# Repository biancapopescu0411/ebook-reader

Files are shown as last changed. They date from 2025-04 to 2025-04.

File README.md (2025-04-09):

# README - OpenBook

**OpenBook** este un sistem portabil pentru citirea cărților electronice, proiectat în jurul microcontrollerului ESP32-C6-WROOM-1-N8. Dispozitivul integrează o serie de componente inteligente pentru stocare, afișare, alimentare și comunicații, toate optimizate pentru eficiență energetică și portabilitate.

## Diagrama bloc
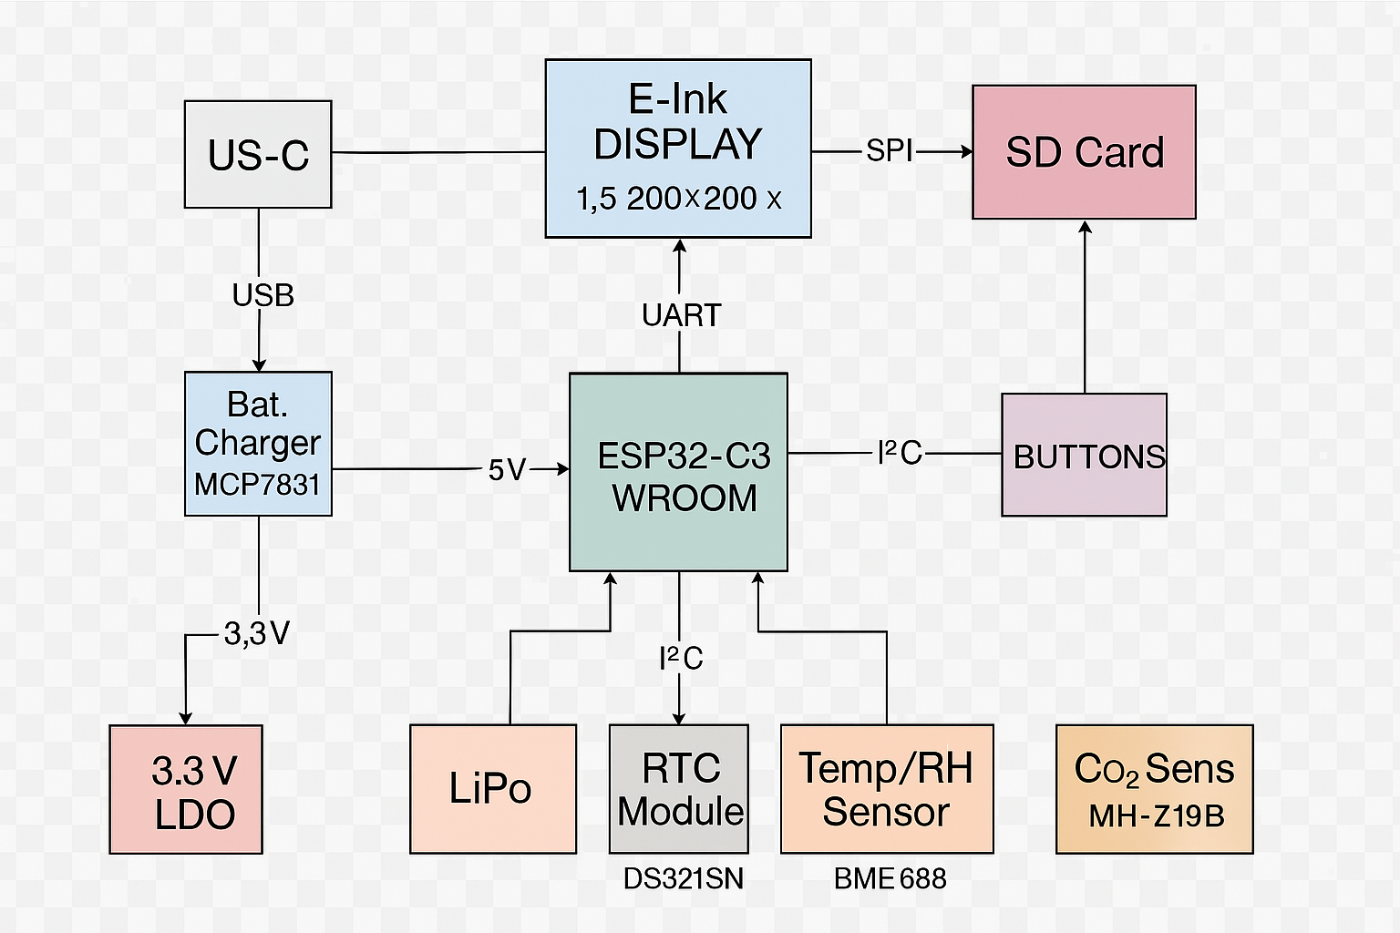
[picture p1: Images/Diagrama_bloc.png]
Diagrama bloc


---

## Componente Hardware & Funcționalitate
### Microcontroller Principal
- **ESP32-C6-WROOM-1-N8**

- Procesor RISC-V 32-bit

- Conectivitate Wi-Fi 6 și Bluetooth 5.0

- Memorie Flash internă de 8MB

- Nivel logic și alimentare: 3.3V

- Responsabil de comunicarea cu senzorii, ecranul EPD, memoria externă și stocarea datelor.

---

## Interfețe de Comunicație

| Interfață | Componente Conectate |
|---|---|
| **I2C**  | BME688, MAX17048, DS3231SN |
| **SPI**  | Display E-Ink, SD Card, Flash Memory |
| **UART** | Serial debug via USB-C (TX/RX) |
| **GPIO** | Butoane, LED-uri, semnale control |

---

## Energie și Alimentare

- Alimentare prin **USB-C** sau baterie **Li-Po**
- Condensatori de decuplare de **100nF** aproape de fiecare pin de alimentare
- Regulator **LDO 3.3V** pentru circuitele logice
- Încărcarea bateriei este gestionată de **MCP73831**
- Plan de masă aplicat pe ambele straturi (**TOP & BOTTOM**) pentru stabilitate electrică

---

## Funcționalitate Detaliată

### ESP32-C6
- Rol: procesor central, interfațare completă cu toate modulele
- Conectat direct la:
  - UART: comunicare cu e-Paper
  - SPI: display, stocare date
  - I2C: senzori și RTC

### Display E-Ink
- Afișare text/imagine cu consum redus
- Interfață SPI dedicată

### Baterie & Protecții
- Baterie conectată la 4 pad-uri pentru economie de spațiu
- Decuplare prin condensatori de 100nF
- Protecții plasate strategic prin via stitching

---

## Structura Proiect
```
├── Hardware
│   ├── schematic_final.sch            # Fișier schematic
│   └── pcb final.brd            # Fișier PCB
├── Manufacturing
│   ├── gerbers.zip             # Fișiere Gerber generate
│   ├── bom.csv            # Bill of Materials
│   └── Pick and place.csv           # Pick and Place file
├── Mechanical
│   ├── exploded.step  # Model 3D exploded (PCB + baterie + ecran + carcasă)
│   └── OpenBook Enclosure.f3z  # Model nativ Fusion360
├── Images
│   ├── 3d.png
│   └── baterie.png
|   └── exploded view.png
|   └── no lid.png
|   └── openbook enclosure.png
|   └── screen view.png
|   └── screen.png
└── README.md
```

## Bill of Materials
| Componenta | Link | Datasheet |
|---|---|---|
| BUTTON | [Model](https://industry.panasonic.com/global/en/products/control/switch/light-touch/number/evqpuj02k) | [Datasheet](https://www.lcsc.com/datasheet/lcsc_datasheet_2201121800_PANASONIC-EVQPUJ02K_C2936858.pdf) |
| CAPACITOR | [Model](https://componentsearchengine.com/part-view/R0402%201%25%20100%20K%20(RC0402FR-07100KL)/YAGEO) | [Datasheet](//efaidnbmnnnibpcajpcglclefindmkaj/https://www.resistor.com/assets/pdf/0402tstd.pdf) |
| CPH3225A | [Model](https://www.snapeda.com/parts/CPH3225A/Seiko+Instruments/view-part/?ref=eda) | [Datasheet](https://octopart.com/datasheet/cph3225a-seiko-25340571) |
| EVQPUJ02K | [Model](https://industry.panasonic.com/global/en/products/control/switch/light-touch/number/evqpuj02k) | [Datasheet](https://www.lcsc.com/datasheet/lcsc_datasheet_2201121800_PANASONIC-EVQPUJ02K_C2936858.pdf) |
| KP-1608SURCK | [Model](https://www.snapeda.com/parts/KP-1608SURCK/Kingbright/view-part/?ref=search&t=LED%200603) | [Datasheet](//efaidnbmnnnibpcajpcglclefindmkaj/https://media.elv.com/file/107153_led_surck1608_data.pdf) |
| USBLC6-2SC6Y | [Model](https://www.snapeda.com/parts/USBLC6-2SC6Y/STMicroelectronics/view-part/?ref=eda) | [Datasheet](https://www.digikey.com/en/htmldatasheets/production/1375342/0/0/1/usblc6-2sc6y) |
| SD0805S020S1R0 | [Model](https://ro.mouser.com/ProductDetail/KYOCERA-AVX/SD0805S020S1R0?qs=jCA%252BPfw4LHbpkAoSnwrdjw%3D%3D) | [Datasheet](https://www.alldatasheet.com/view.jsp?Searchword=SD0805S&sField=2) |
| PGB1010603MR | [Model](https://www.snapeda.com/parts/PGB1010603MR/Littelfuse/view-part/?ref=eda) | [Datasheet](https://www.alldatasheet.com/view.jsp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) |
| BD5229G-TR  | [Model](https://componentsearchengine.com/part-view/BD5229G-TR/ROHM%20Semiconductor) | [Datasheet](https://www.lcsc.com/datasheet/lcsc_datasheet_2201131330_ROHM-Semicon-BD5229G-TR_C962636.pdf) |
| XC6220A331MR-G | [Model](https://componentsearchengine.com/part-view/XC6220A331MR-G/Torex) | [Datasheet](https://www.alldatasheet.com/view.jsp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) |
| XC6220A331MR-G | [Model](https://componentsearchengine.com/part-view/XC6220A331MR-G/Torex) | [Datasheet](https://www.alldatasheet.com/view.jsp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) |
| USB4110-GF-A  | [Model](https://componentsearchengine.com/part-view/USB4110-GF-A/GCT%20(GLOBAL%20CONNECTOR%20TECHNOLOGY)) | [Datasheet](//efaidnbmnnnibpcajpcglclefindmkaj/https://gct.co/files/drawings/usb4110.pdf) |
| Adafruit | [Model](https://eu.mouser.com/ProductDetail/Adafruit/4208?qs=PzGy0jfpSMtbScLbr0L5dw%3D%3D) | [Datasheet](https://www.arrow.com/en/manufacturers/adafruit-industries/datasheets) |
| Bobina | [Model](https://store.comet.srl.ro/Catalogue/Product/43497/) | [Datasheet](https://www.scribd.com/document/814581278/Datasheet-Bobina) |
| PFMF | [Model](https://www.mouser.co.uk/ProductDetail/EPCOS-TDK/B72520T0350K062?qs=dEfas%2FXlABIszF52uu7vrg%3D%3D) | [Datasheet](https://ro.mouser.com/c/ds/circuit-protection/thermistors/resettable-fuses-pptc/?m=Schurter&series=PFMF) |
| DMG2305UX-7 | [Model](https://componentsearchengine.com/part-view/DMG2305UX-7/Diodes%20Incorporated) | [Datasheet](//efaidnbmnnnibpcajpcglclefindmkaj/https://www.mouser.com/datasheet/2/115/DMG2305UX-266242.pdf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) |
| Si1308EDL-T1-GE3 | [Model](https://componentsearchengine.com/part-view/SI1308EDL-T1-GE3/Vishay) | [Datasheet](https://www.alldatasheet.com/view.jsp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) |
| R0402 | [Model](https://componentsearchengine.com/part-view/R0402%201%25%20100%20K%20(RC0402FR-07100KL)/YAGEO) | [Datasheet](//efaidnbmnnnibpcajpcglclefindmkaj/https://www.resistor.com/assets/pdf/0402tstd.pdf) |
| BME680 | [Model](https://www.snapeda.com/parts/BME680/Bosch/view-part/?welcome=home) | [Datasheet](//efaidnbmnnnibpcajpcglclefindmkaj/https://www.bosch-sensortec.com/media/boschsensortec/downloads/datasheets/bst-bme680-ds001.pdf) |
| SMD Solder | [Model](https://grabcad.com/library/solder-jumpers-1) | [Datasheet]() |
| W25Q512JVEIQ | [Model](https://www.snapeda.com/parts/ESP32-C6-WROOM-1-N8/Espressif+Systems/view-part/?ref=eda) | [Datasheet](//efaidnbmnnnibpcajpcglclefindmkaj/https://www.mouser.com/datasheet/2/949/W25Q512JV_SPI_RevB_06252019_KMS-2487502.pdf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) |
| ESP32-C6-WROOM-1-N8 | [Model](https://www.snapeda.com/parts/ESP32-C6-WROOM-1-N8/Espressif+Systems/view-part/?ref=eda) | [Datasheet](//efaidnbmnnnibpcajpcglclefindmkaj/https://www.mouser.com/catalog/specsheets/Espressif_ESP32_C6_WROOM_1%20_Datasheet_V0.1_PRELIMINARY_en.pdf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) |
| DS3231SN# | [Model](https://www.snapeda.com/parts/DS3231SN%23/Analog+Devices/view-part/?ref=eda) | [Datasheet](https://www.alldatasheet.com/view.jsp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) |
| MAX17048G+T10 | [Model](https://www.snapeda.com/parts/MAX17048G+T10/Analog+Devices/view-part/?ref=eda) | [Datasheet](https://www.alldatasheet.com/view.jsp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) |
| MCP73831T-5ACI/OT | [Model](https://www.mouser.co.uk/ProductDetail/Microchip-Technology/MCP73831T-5ACI-OT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) | [Datasheet](//efaidnbmnnnibpcajpcglclefindmkaj/https://ww1.microchip.com/downloads/en/DeviceDoc/MCP73831-Family-Data-Sheet-DS20001984H.pdf) |

## Detaliere Pini Utilizați (ESP32-C6 / U2)

| Pin ESP32 | Funcție Principală | Componentă Conectată / Scop |
| :--- | :--- | :--- |
| IO3 | RESET | SW2, IC5 |
| IO5 | GPIO | J4 (EPD_DC) |
| IO6 | SPI SCK | J4 (EPD_SCK), J3 (SD_CLK) |
| IO7 | SPI MOSI | J4 (EPD_DIN), J3 (SD_DI) |
| IO8 | BOOT | SW1 (Buton Boot) |
| IO10 | GPIO / SPI CS | J3 (SD_CS) |
| IO11 | GPIO / SPI CS | J4 (EPD_CS) |
| IO13 | USB D- | J2 (USB-C D-) via D2 |
| IO14 | USB D+ | J2 (USB-C D+) via D2 |
| IO19 | I2C SDA | IC2 (RTC SDA), IC3 (BME SDA/SDO) |
| IO20 | I2C SCL | IC2 (RTC SCL), IC3 (BME SCL/SCK) |
| IO21 | GPIO | J4 (EPD_RST) |
| IO26 | GPIO | J4 (EPD_BUSY) |
| IO27 | SPI MISO | J4 (EPD_DOUT), J3 (SD_DO) |
| EN | Enable | Pull-up la 3.3V |
| VDD | Power | 3.3V |
| GND | Ground | Ground |
| IO12 | Neutilizat | - |
| IO24 | Neutilizat | - |
| IO25 | Neutilizat | - |

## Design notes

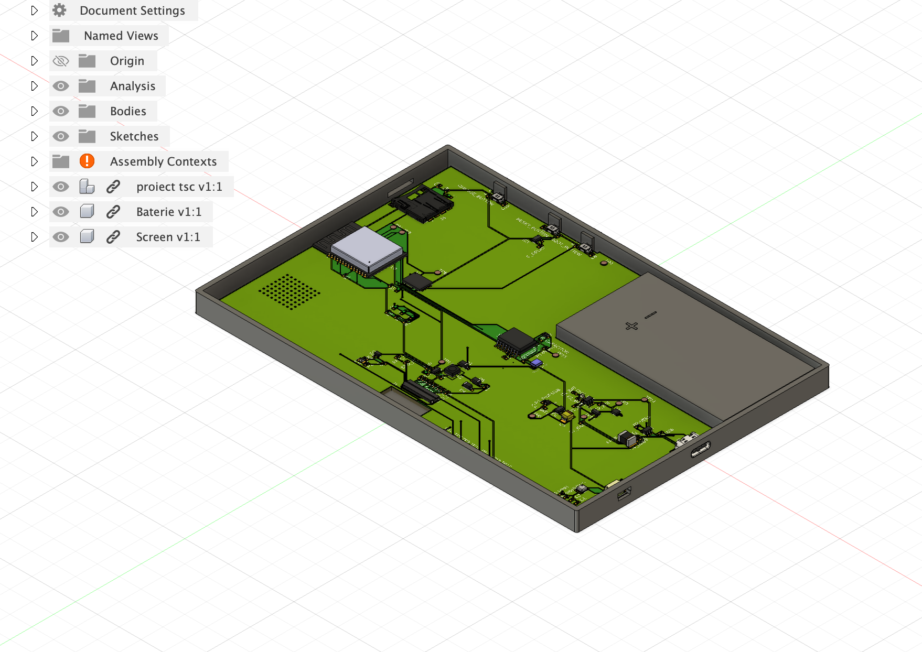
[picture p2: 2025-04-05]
Images/no lid.png

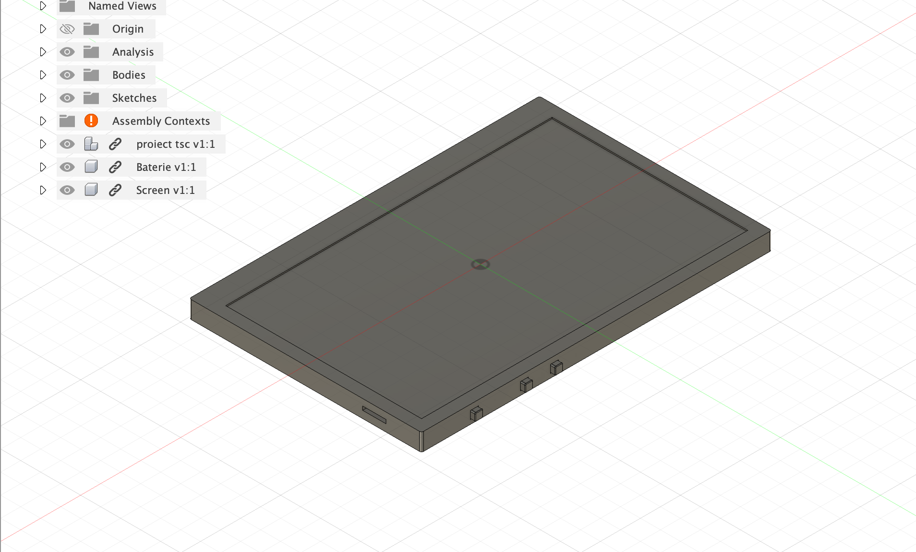
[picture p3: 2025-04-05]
Images/screen view.png

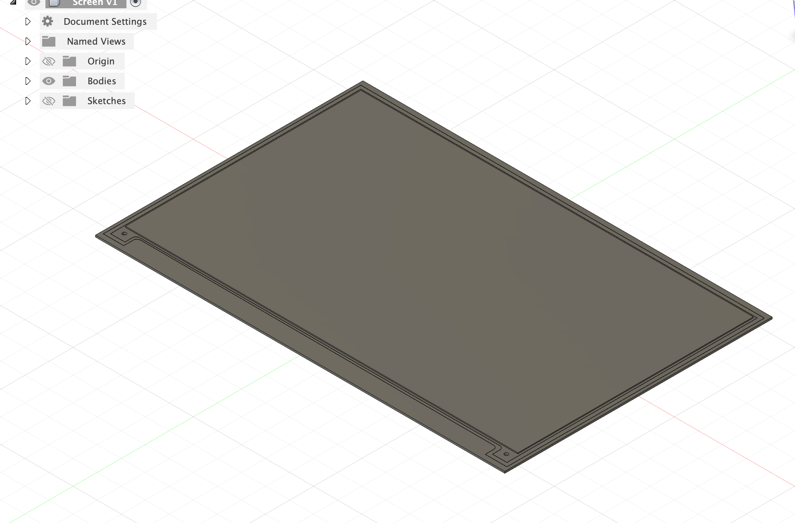
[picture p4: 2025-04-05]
Images/screen.png

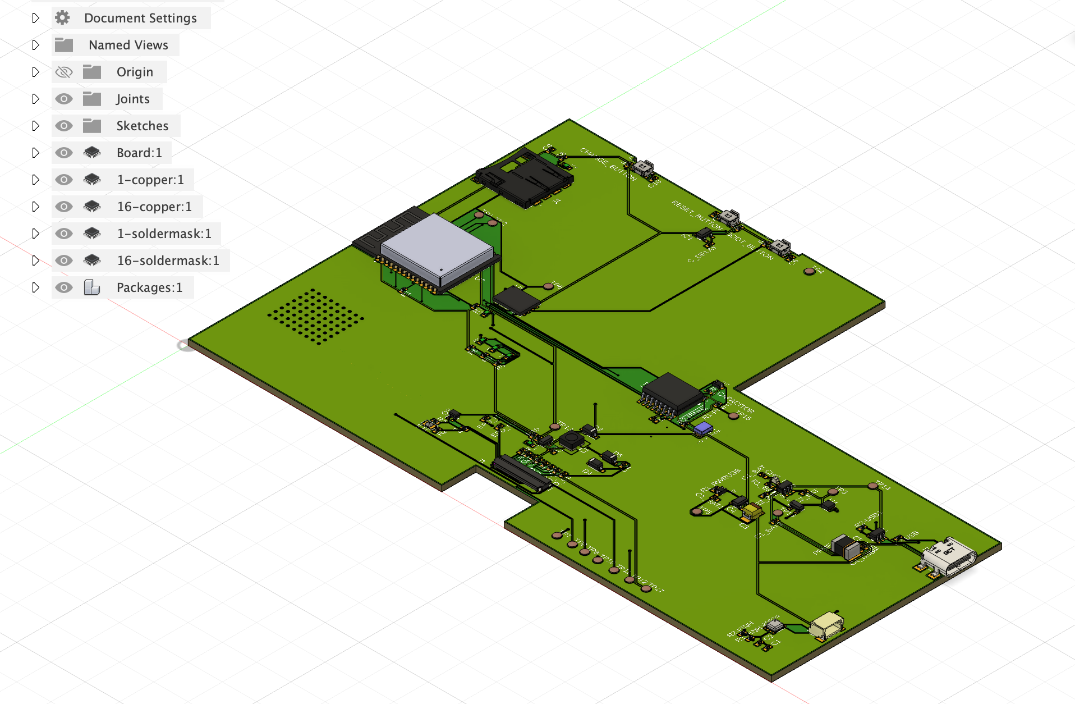
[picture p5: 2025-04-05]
Images/3d.png

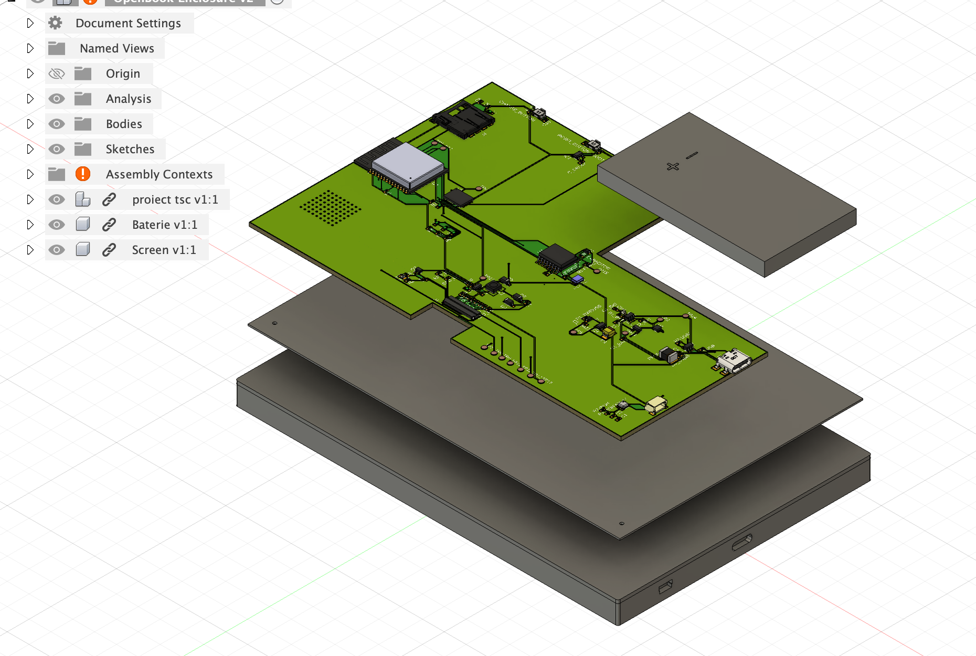
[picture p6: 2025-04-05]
Images/exploded view.png

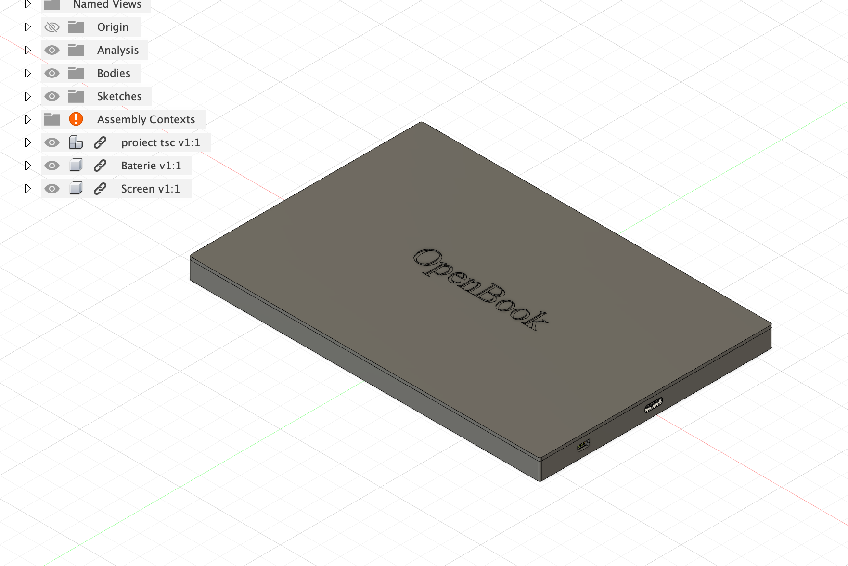
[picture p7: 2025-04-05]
Images/openbook enclosure.png

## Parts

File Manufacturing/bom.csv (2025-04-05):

Qty | Value | Device | Package | Parts | Description | ARROW_PART_NUMBER | ARROW_PRICE-STOCK | ATTR | AVAILABILITY | CENTROID_NOT_SPECIFIED | CHECK_PRICES | COPYRIGHT | DATASHEET | DESCRIPTION | DIGIKEY_DESCRIPTION | DIGIKEY_PART_NUMBER | HEIGHT | LEAD_FREE | MANUFACTURER_NAME | MANUFACTURER_PART_NUMBER | MF | MFR_NAME | MOUSER_PART_NUMBER | MOUSER_PRICE-STOCK | MOUSER_TESTING_PART_NUMBER | MOUSER_TESTING_PRICE-STOCK | MP | MPN | PACKAGE | POPULARITY | PREFIX | PRICE | PROD_ID | PURCHASE-URL | ROHS | SNAPEDA_LINK | SPICEMODEL | SPICEPREFIX | TEMPERATURE_RANGE_HIGH | TEMPERATURE_RANGE_LOW | TP_SIGNAL_NAME | VALUE
1 |  | ADAFRUIT_LEDCHIP-LED0603 | ADAFRUIT_CHIP-LED0603 | CHG_LED | LED
1 |  | BUTTON_CUSYOMV1 | MYBUTTON | BOOT_BUTTON
1 |  | SJ | SJ | SJ1 | SMD solder JUMPER |  |  |  |  |  |  |  |  |  |  |  |  |  |  |  |  |  |  |  |  |  |  |  |  | 3
1 | 0.1uF/50V | EAGLE-LTSPICE_CC0402 | EAGLE-LTSPICE_C0402 | EPD_C5 | CAPACITOR, European symbol |  |  |  |  |  |  |  |  |  |  |  |  |  |  |  |  |  |  |  |  |  |  |  |  |  |  |  |  |  |  |  | NONE | C
1 | 0.47 | ESP32_WROVER_EAGLE-LTSPICE_RR0402 | ESP32_WROVER_EAGLE-LTSPICE_R0402 | R3 | RESISTOR, European symbol |  |  |  |  |  |  |  |  |  |  |  |  |  |  |  |  |  |  |  |  |  |  |  |  |  |  |  |  |  |  |  | NONE | R
1 | 100K | ESP32_WROVER_EAGLE-LTSPICE_RR0402 | ESP32_WROVER_EAGLE-LTSPICE_R0402 | R1_RWRUSB | RESISTOR, European symbol |  |  |  |  |  |  |  |  |  |  |  |  |  |  |  |  |  |  |  |  |  |  |  |  |  |  |  |  |  |  |  | NONE | R
8 | 100nF | EAGLE-LTSPICE_CC0402 | EAGLE-LTSPICE_C0402 | C1, C2, C4_USB, C6, C8, C9, C10, C_DELAY | CAPACITOR, European symbol |  |  |  |  |  |  |  |  |  |  |  |  |  |  |  |  |  |  |  |  |  |  |  |  |  |  |  |  |  |  |  | NONE | C
1 | 100uF TANT | RCL_CPOL-EUCT3528 | RCL_CT3528 | C3 | POLARIZED CAPACITOR, European symbol |  |  |  |  |  |  |  |  |  |  |  |  |  |  |  |  |  |  |  |  |  |  |  |  | 0 |  |  |  |  |  |  |  | C
16 | 10K | ESP32_WROVER_EAGLE-LTSPICE_RR0402 | ESP32_WROVER_EAGLE-LTSPICE_R0402 | R1, R1-PINH, R1-PINH1, R2-PINH, R2-PINH1, R4, R5, R6, R7, R8, R9, R10, R_BOOT, R_CHANGE, R_CL1, R_RESET | RESISTOR, European symbol |  |  |  |  |  |  |  |  |  |  |  |  |  |  |  |  |  |  |  |  |  |  |  |  |  |  |  |  |  |  |  | NONE | R
1 | 10uF | EAGLE-LTSPICE_CC0402 | EAGLE-LTSPICE_C0402 | C7 | CAPACITOR, European symbol |  |  |  |  |  |  |  |  |  |  |  |  |  |  |  |  |  |  |  |  |  |  |  |  |  |  |  |  |  |  |  | NONE | C
1 | 112A-TAAR-R03_ATTEND | 112A-TAAR-R03_ATTEND | 112ATAARR03ATTEND | J4 | Micro SD Card Socket, Push-Push Type, Top Mount, SMT, H=1.83mm, 10u |  |  |  |  |  |  |  |  | Micro SD Card Socket | Push-Push Type | Top Mount | SMT | H=1.83mm | 10u |  |  | 1.9mm |  | ATTEND | 112A-TAAR-R03 ATTEND
1 | 15 | ESP32_WROVER_EAGLE-LTSPICE_RR0402 | ESP32_WROVER_EAGLE-LTSPICE_R0402 | R_CAPACITOR | RESISTOR, European symbol |  |  |  |  |  |  |  |  |  |  |  |  |  |  |  |  |  |  |  |  |  |  |  |  |  |  |  |  |  |  |  | NONE | R
1 | 1uF | EAGLE-LTSPICE_CC0402 | EAGLE-LTSPICE_C0402 | C5 | CAPACITOR, European symbol |  |  |  |  |  |  |  |  |  |  |  |  |  |  |  |  |  |  |  |  |  |  |  |  |  |  |  |  |  |  |  | NONE | C
9 | 1uF/50V | EAGLE-LTSPICE_CC0402 | EAGLE-LTSPICE_C0402 | EPD_C1, EPD_C2, EPD_C6, EPD_C7, EPD_C8, EPD_C9, EPD_C10, EPD_C11, EPD_C12 | CAPACITOR, European symbol |  |  |  |  |  |  |  |  |  |  |  |  |  |  |  |  |  |  |  |  |  |  |  |  |  |  |  |  |  |  |  | NONE | C
1 | 2.2 | ESP32_WROVER_EAGLE-LTSPICE_RR0402 | ESP32_WROVER_EAGLE-LTSPICE_R0402 | R2 | RESISTOR, European symbol |  |  |  |  |  |  |  |  |  |  |  |  |  |  |  |  |  |  |  |  |  |  |  |  |  |  |  |  |  |  |  | NONE | R
1 | 200 | ESP32_WROVER_EAGLE-LTSPICE_RR0402 | ESP32_WROVER_EAGLE-LTSPICE_R0402 | R1_BAT | RESISTOR, European symbol |  |  |  |  |  |  |  |  |  |  |  |  |  |  |  |  |  |  |  |  |  |  |  |  |  |  |  |  |  |  |  | NONE | R
1 | 20V/4.2A/52mΩ/1.4W | ESP32_WROVER_SPARKFUN-DISCRETESEMI_MOSFET_PCH-DMG2305UX-7 | ESP32_WROVER_SPARKFUN-DISCRETESEMI_SOT23-3 | Q2 | P-channel MOSFETs |  |  |  |  |  |  |  |  |  |  |  |  |  |  |  |  |  |  |  |  |  |  |  |  |  |  |  | TRAN-14388 |  |  |  |  |  |  |  |  | 20V/4.2A/52mΩ/1.4W
1 | 20V/4.2A/52mΩ/1.4W | ESP32_WROVER_SPARKFUN-DISCRETESEMI_MOSFET_PCH-DMG2305UX-7 | ESP32_WROVER_SPARKFUN-DISCRETESEMI_SOT23-3 | Q1 | P-channel MOSFETs |  |  | DMG2305UX-7 |  |  |  |  |  |  |  |  |  |  |  |  |  |  |  |  |  |  |  |  |  |  |  |  | TRAN-14388 |  |  |  |  |  |  |  |  | 20V/4.2A/52mΩ/1.4W
1 | 2K | ESP32_WROVER_EAGLE-LTSPICE_RR0402 | ESP32_WROVER_EAGLE-LTSPICE_R0402 | R2_BAT | RESISTOR, European symbol |  |  |  |  |  |  |  |  |  |  |  |  |  |  |  |  |  |  |  |  |  |  |  |  |  |  |  |  |  |  |  | NONE | R
5 | 4.7uF | EAGLE-LTSPICE_CC0402 | EAGLE-LTSPICE_C0402 | C1_BAT, C1_BAT1, C1_BAT2, C2_BAT, C5_USB | CAPACITOR, European symbol |  |  |  |  |  |  |  |  |  |  |  |  |  |  |  |  |  |  |  |  |  |  |  |  |  |  |  |  |  |  |  | NONE | C
1 | 4.7uF/25V | EAGLE-LTSPICE_CC0402 | EAGLE-LTSPICE_C0402 | C4 | CAPACITOR, European symbol |  |  |  |  |  |  |  |  |  |  |  |  |  |  |  |  |  |  |  |  |  |  |  |  |  |  |  |  |  |  |  | NONE | C
2 | 5k1 | ESP32_WROVER_EAGLE-LTSPICE_RR0402 | ESP32_WROVER_EAGLE-LTSPICE_R0402 | R2-USB, R2-USB1 | RESISTOR, European symbol |  |  |  |  |  |  |  |  |  |  |  |  |  |  |  |  |  |  |  |  |  |  |  |  |  |  |  |  |  |  |  | NONE | R
1 | 68uH | 744043680IND_4828-WE-TPC_WRE | IND_4828-WE-TPC_WRE | L1 |  |  |  |  |  |  |  | Copyright (C) 2024 Ultra Librarian. All rights reserved. |  |  |  |  |  |  |  | 744043680 |  | Wurth Electronics
1 | BD5229G-TR | BD5229G-TR | SOT95P280X125-5N | IC1 | Voltage Detector with Adjustable Delay Time: CMOS processes are utilized to develop high precision, low current consumption CMOS reset ICs that allow arbitrary setting of the delay time. The extensive lineup includes both Nch Open Drain and CMOS output types in a wide range of detection voltages (from 2.3V to 6.0V, in 0.1V steps), enabling selection of the ideal solution based on customer requirements. In addition, the entire series is of course both lead-free and RoHS-compliant. |  |  |  |  |  |  |  |  | Voltage Detector with Adjustable Delay Time: CMOS processes are utilized to develop high precision | low current consumption CMOS reset ICs that allow arbitrary setting of the delay time. The extensive lineup includes both Nch Open Drain and CMOS output types in a wide range of detection voltages (from 2.3V to 6.0V | in 0.1V steps) | enabling selection of the ideal solution based on customer requirements. In addition | the entire series is of course both lead-free and RoHS-compliant. |  |  | 1.25mm |  | ROHM Semiconductor | BD5229G-TR |  |  | 755-BD5229G-TR | https://www.mouser.co.uk/ProductDetail/ROHM-Semiconductor/BD5229G-TR?qs=4kLU8WoGk0vvnhrrYwdszw%3D%3D
1 | BME688 | ESP32_WROVER_BME680_BME680 | ESP32_WROVER_BME680_PSON80P300X300X100-8N | SENSOR2 | Integrated Environmental Unit |  |  |  | Unavailable |  |  |  |  | Integrated Environmental Unit |  |  |  |  |  |  | Bosch Sensortec |  |  |  |  |  | BME680 |  | LGA-8 Bosch Tools |  |  | None
1 | BUTTON_CUSYOMV1 | BUTTON_CUSYOMV1 | MYBUTTON | CHANGE_BUTTON
1 | CPH3225A | CPH3225A | CAPCP3225X100N | C10_SUPERCAP | Cap 0.011F 3.3V 1210 Flat Check availability |  |  |  | Not in stock |  | https://www.snapeda.com/parts/CPH3225A/Seiko+Instruments/view-part/?ref=eda |  |  | 11 mF (EDLC) Supercapacitor 3.3 V 1210 (3225 Metric) - - |  |  |  |  |  |  | Seiko Instruments |  |  |  |  |  | CPH3225A |  | 1210 Seiko |  |  | None |  | https://www.snapeda.com/api/url_track_click_mouser/?unipart_id=562593&manufacturer=Seiko Instruments&part_name=CPH3225A&search_term=None |  | https://www.snapeda.com/parts/CPH3225A/Seiko+Instruments/view-part/?ref=snap
1 | DS3231SN# | DS3231SN# | SOIC127P1032X265-16N | U3 | Real Time Clock Serial 16-Pin SOIC W T/R Check availability |  |  |  | In Stock |  | https://www.snapeda.com/parts/DS3231SN%23/Analog+Devices/view-part/?ref=eda |  |  | Extremely Accurate I²C-Integrated RTC/TCXO/Crystal |  |  |  |  |  |  | Analog Devices |  |  |  |  |  | DS3231SN# |  | SOIC-16 Maxim |  |  | None |  | https://www.snapeda.com/api/url_track_click_mouser/?unipart_id=99048&manufacturer=Analog Devices&part_name=DS3231SN#&search_term=None |  | https://www.snapeda.com/parts/DS3231SN%23/Analog+Devices/view-part/?ref=snap
1 | ESP32-C6-WROOM-1-N8 | ESP32-C6-WROOM-1-N8 | XCVR_ESP32-C6-WROOM-1-N8 | U2 | Check availability |  |  |  | In Stock |  | https://www.snapeda.com/parts/ESP32-C6-WROOM-1-N8/Espressif+Systems/view-part/?ref=eda |  |  | Multiprotocol Modules ESP32-C6 module | Wi-Fi 6 in 2.4 GHz band | Bluetooth 5 | Zigbee 3.0 and Thread. ESP34-WROOM Compatible - ENGINEERING SAMPLE |  |  |  |  |  |  | Espressif Systems |  |  |  |  |  | ESP32-C6-WROOM-1-N8 |  | None |  |  | None |  |  |  | https://www.snapeda.com/parts/ESP32-C6-WROOM-1-N8/Espressif+Systems/view-part/?ref=snap
1 | ESP32C6_VARISTORCN1812 | ESP32C6_VARISTORCN1812 | ESP32C6_VARISTOR_CT/CN1812 | PFMF.050.1 | VARISTOR |  |  |  |  |  |  |  |  |  |  |  |  |  |  |  |  |  |  |  |  |  |  |  |  | 0
1 | ESP32_WROVER_AVX---SD0805S020S1R0_AVX_SD0805S020S1R0_0_0AVX_SD0805S020S1R0_0_0 | ESP32_WROVER_AVX---SD0805S020S1R0_AVX_SD0805S020S1R0_0_0AVX_SD0805S020S1R0_0_0 | ESP32_WROVER_AVX---SD0805S020S1R0_AVX_SD0805S020S1R0_0 | D7 | Schottky Barrier Rectifier Diode |  |  |  |  | No |  |  | http://datasheets.avx.com/schottky.pdf |  | DIODE SCHOTTKY 20V 1A 0805 | 478-7800-1-ND |  | yes |  |  | AVX |  | 581-SD0805S020S1R0 |  |  |  |  |  | 0805 (2012 metric) |  | D |  |  |  | yes |  |  |  | +125°C | -55°C
1 | ESP32_WROVER_SPARKFUN-IC-POWER_MCP73831 | ESP32_WROVER_SPARKFUN-IC-POWER_MCP73831 | ESP32_WROVER_SPARKFUN-IC-POWER_SOT23-5 | MCP73831 | MCP73831T Li-Ion, Li-Pol Controller |  |  |  |  |  |  |  |  |  |  |  |  |  |  |  |  |  |  |  |  |  |  |  |  |  |  |  | IC-09995
1 | FH34SRJ-24S-0.5SH_99_ | FH34SRJ-24S-0.5SH_99_ | FH34SRJ24S05SH99 | J1 | (0.50mm) Surface Mount, Right Angle |  |  |  |  |  |  |  |  | 24 Position FFC | FPC Connector Contacts | (0.50mm) Surface Mount | Right Angle |  |  | 1.1mm |  | Hirose | FH34SRJ-24S-0.5SH(99) |  |  | 798-FH34SRJ24S05SH99 | https://www.mouser.co.uk/ProductDetail/Hirose-Connector/FH34SRJ-24S-0.5SH99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
1 | MAX17048G+T10 | MAX17048G+T10 | SON50P200X200X80-9N | U4 | Check availability |  |  |  | In Stock |  | https://www.snapeda.com/parts/MAX17048G+T10/Analog+Devices/view-part/?ref=eda |  |  | 3µA 1-Cell/2-Cell Fuel Gauge with ModelGauge |  |  |  |  |  |  | Analog Devices |  |  |  |  |  | MAX17048G+T10 |  | TDFN-8 Maxim |  |  | None |  | https://www.snapeda.com/api/url_track_click_mouser/?unipart_id=329239&manufacturer=Analog Devices&part_name=MAX17048G+T10&search_term=None |  | https://www.snapeda.com/parts/MAX17048G+T10/Analog+Devices/view-part/?ref=snap
3 | MBR0530 | MBR0530 | SOD3716X135N | D3, D4, D5 | ON SEMICONDUCTOR - MBR0530 - DIODE, SCHOTTKY, 0.5A, 30V, SOD-123 |  |  |  | In Stock |  | https://www.snapeda.com/parts/MBR0530/Onsemi/view-part/?ref=eda |  |  | Diode Schottky 30 V 500mA Surface Mount SOD-123 |  |  |  |  |  |  | ON Semiconductor |  |  |  |  |  | MBR0530 |  | SOD-123-2 ON Semiconductor |  |  | None |  | https://www.snapeda.com/api/url_track_click_mouser/?unipart_id=179458&manufacturer=ON Semiconductor&part_name=MBR0530&search_term=None |  | https://www.snapeda.com/parts/MBR0530/Onsemi/view-part/?ref=snap
6 | PGB1010603MR | PGB1010603MR | DIOC1608X36N | D6, D8, D9, D10, D11, D12 | Check availability |  |  |  | In Stock |  | https://www.snapeda.com/parts/PGB1010603MR/Littelfuse/view-part/?ref=eda |  |  | 150V (Typ) Clamp - Ipp Tvs Diode Surface Mount 0603 (1608 Metric) |  |  |  |  |  |  | Littelfuse Inc. |  |  |  |  |  | PGB1010603MR |  | 0603 Littelfuse Inc. |  |  | None |  | https://www.snapeda.com/api/url_track_click_mouser/?unipart_id=5659453&manufacturer=Littelfuse Inc.&part_name=PGB1010603MR&search_term=None |  | https://www.snapeda.com/parts/PGB1010603MR/Littelfuse/view-part/?ref=snap
1 | QWIIC_RIGHT_ANGLE | QWIIC_CONNECTORJS-1MM | JST04_1MM_RA | J3 | SparkFun I2C Standard Qwiic Connector |  |  |  |  |  |  |  |  |  |  |  |  |  |  |  |  |  |  |  |  |  |  |  |  |  |  |  | CONN-13694 |  |  |  |  |  |  |  |  | QWIIC_RIGHT_ANGLE
1 | RESET_BUTTON | BUTTON_CUSYOMV1 | MYBUTTON | RESET_BUTTON
1 | SAMACSYS_PARTS_USB4110-GF-A | SAMACSYS_PARTS_USB4110-GF-A | SAMACSYS_PARTS_USB4110GFA | J2 | CONN USB 2.0 TYPE-C R/A SMT |  |  |  |  |  |  |  |  | CONN USB 2.0 TYPE-C R/A SMT |  |  | 3.26mm |  | GCT (GLOBAL CONNECTOR TECHNOLOGY) | USB4110-GF-A |  |  | 640-USB4110-GF-A | https://www.mouser.co.uk/ProductDetail/GCT/USB4110-GF-A?qs=KUoIvG%2F9IlYiZvIXQjyJeA%3D%3D
1 | SD0805S020S1R0 | ESP32_WROVER_AVX---SD0805S020S1R0_AVX_SD0805S020S1R0_0_0AVX_SD0805S020S1R0_0_0 | ESP32_WROVER_AVX---SD0805S020S1R0_AVX_SD0805S020S1R0_0 | D2 | Schottky Barrier Rectifier Diode |  |  | SD0805S020S1R0 |  | No |  |  | http://datasheets.avx.com/schottky.pdf |  | DIODE SCHOTTKY 20V 1A 0805 | 478-7800-1-ND |  | yes |  |  | AVX |  | 581-SD0805S020S1R0 |  |  |  |  |  | 0805 (2012 metric) |  | D |  |  |  | yes |  |  |  | +125°C | -55°C
1 | SI1308EDL-T1-GE3 | SI1308EDL-T1-GE3 | SOT65P210X110-3N | Q3 | MOSFET N-Ch 30V 1.5A TrenchFET SC70 Vishay Si1308EDL-T1-GE3 N-channel MOSFET Transistor, 1.5 A, 30 V, 3-Pin SC-70 |  |  |  | In Stock |  | https://www.snapeda.com/parts/SI1308EDL-T1-GE3/Vishay+Siliconix/view-part/?ref=eda |  |  | Si1308EDL-T1-GE3 N-channel MOSFET Transistor | 1.5 A | 30 V | 3-Pin SC-70 | Siliconix / Vishay SI1308EDL-T1-GE3 |  |  |  |  |  |  | Vishay Siliconix |  |  |  |  |  | SI1308EDL-T1-GE3 |  | SOT-323 Vishay Semiconductor |  |  | None |  | https://www.snapeda.com/api/url_track_click_mouser/?unipart_id=274603&manufacturer=Vishay Siliconix&part_name=SI1308EDL-T1-GE3&search_term=None |  | https://www.snapeda.com/parts/SI1308EDL-T1-GE3/Vishay+Siliconix/view-part/?ref=snap
17 | TPTP20R | TPTP20R | TP20R | TP1, TP2, TP3, TP4, TP5, TP6, TP7, TP8, TP9, TP10, TP11, TP12, TP13, TP14, TP15, TP16, TP17 | Test pad |  |  |  |  |  |  |  |  |  |  |  |  |  |  |  |  |  |  |  |  |  |  |  |  | 2
1 | USBLC6-2SC6Y | USBLC6-2SC6Y | SOT95P280X145-6N | D1 | Low Cap. ESD Protection Auto SOT-23-6 STMicroelectronics USBLC6-2SC6Y, Dual Uni-Directional TVS Diode Array, 6-Pin SOT-23 |  |  |  | In Stock |  | https://www.snapeda.com/parts/USBLC6-2SC6Y/STMicroelectronics/view-part/?ref=eda |  |  | 17V Clamp 5A (8/20µs) Ipp Tvs Diode Surface Mount SOT-23-6 |  |  |  |  |  |  | STMicroelectronics |  |  |  |  |  | USBLC6-2SC6Y |  | SOT-23-6 STMicroelectronics |  |  | None |  |  |  | https://www.snapeda.com/parts/USBLC6-2SC6Y/STMicroelectronics/view-part/?ref=snap
1 | W25Q512JVEIQ | W25Q512JVEIQ | SON127P600X800X80-9N | U1 | Check availability |  |  |  | In Stock |  | https://www.snapeda.com/parts/W25Q512JVEIQ/Winbond+Electronics/view-part/?ref=eda |  |  | FLASH - NOR Memory IC 512Mb (64M x 8) SPI - Quad I/O 133 MHz 8-WSON (8x6) |  |  |  |  |  |  | Winbond Electronics |  |  |  |  |  | W25Q512JVEIQ |  | Package |  |  | None |  |  |  | https://www.snapeda.com/parts/W25Q512JVEIQ/Winbond+Electronics/view-part/?ref=snap
1 | XC6220A331MR-G | XC6220A331MR-G | SOT95P280X120-5N | IC4 | LDO Voltage Regulators |  |  |  |  |  |  |  |  | LDO Voltage Regulators |  |  | 1.2mm |  | Torex | XC6220A331MR-G |  |  | 865-XC6220A331MR-G | https://www.mouser.co.uk/ProductDetail/Torex-Semiconductor/XC6220A331MR-G?qs=AsjdqWjXhJ8ZSWznL1J0gg%3D%3D

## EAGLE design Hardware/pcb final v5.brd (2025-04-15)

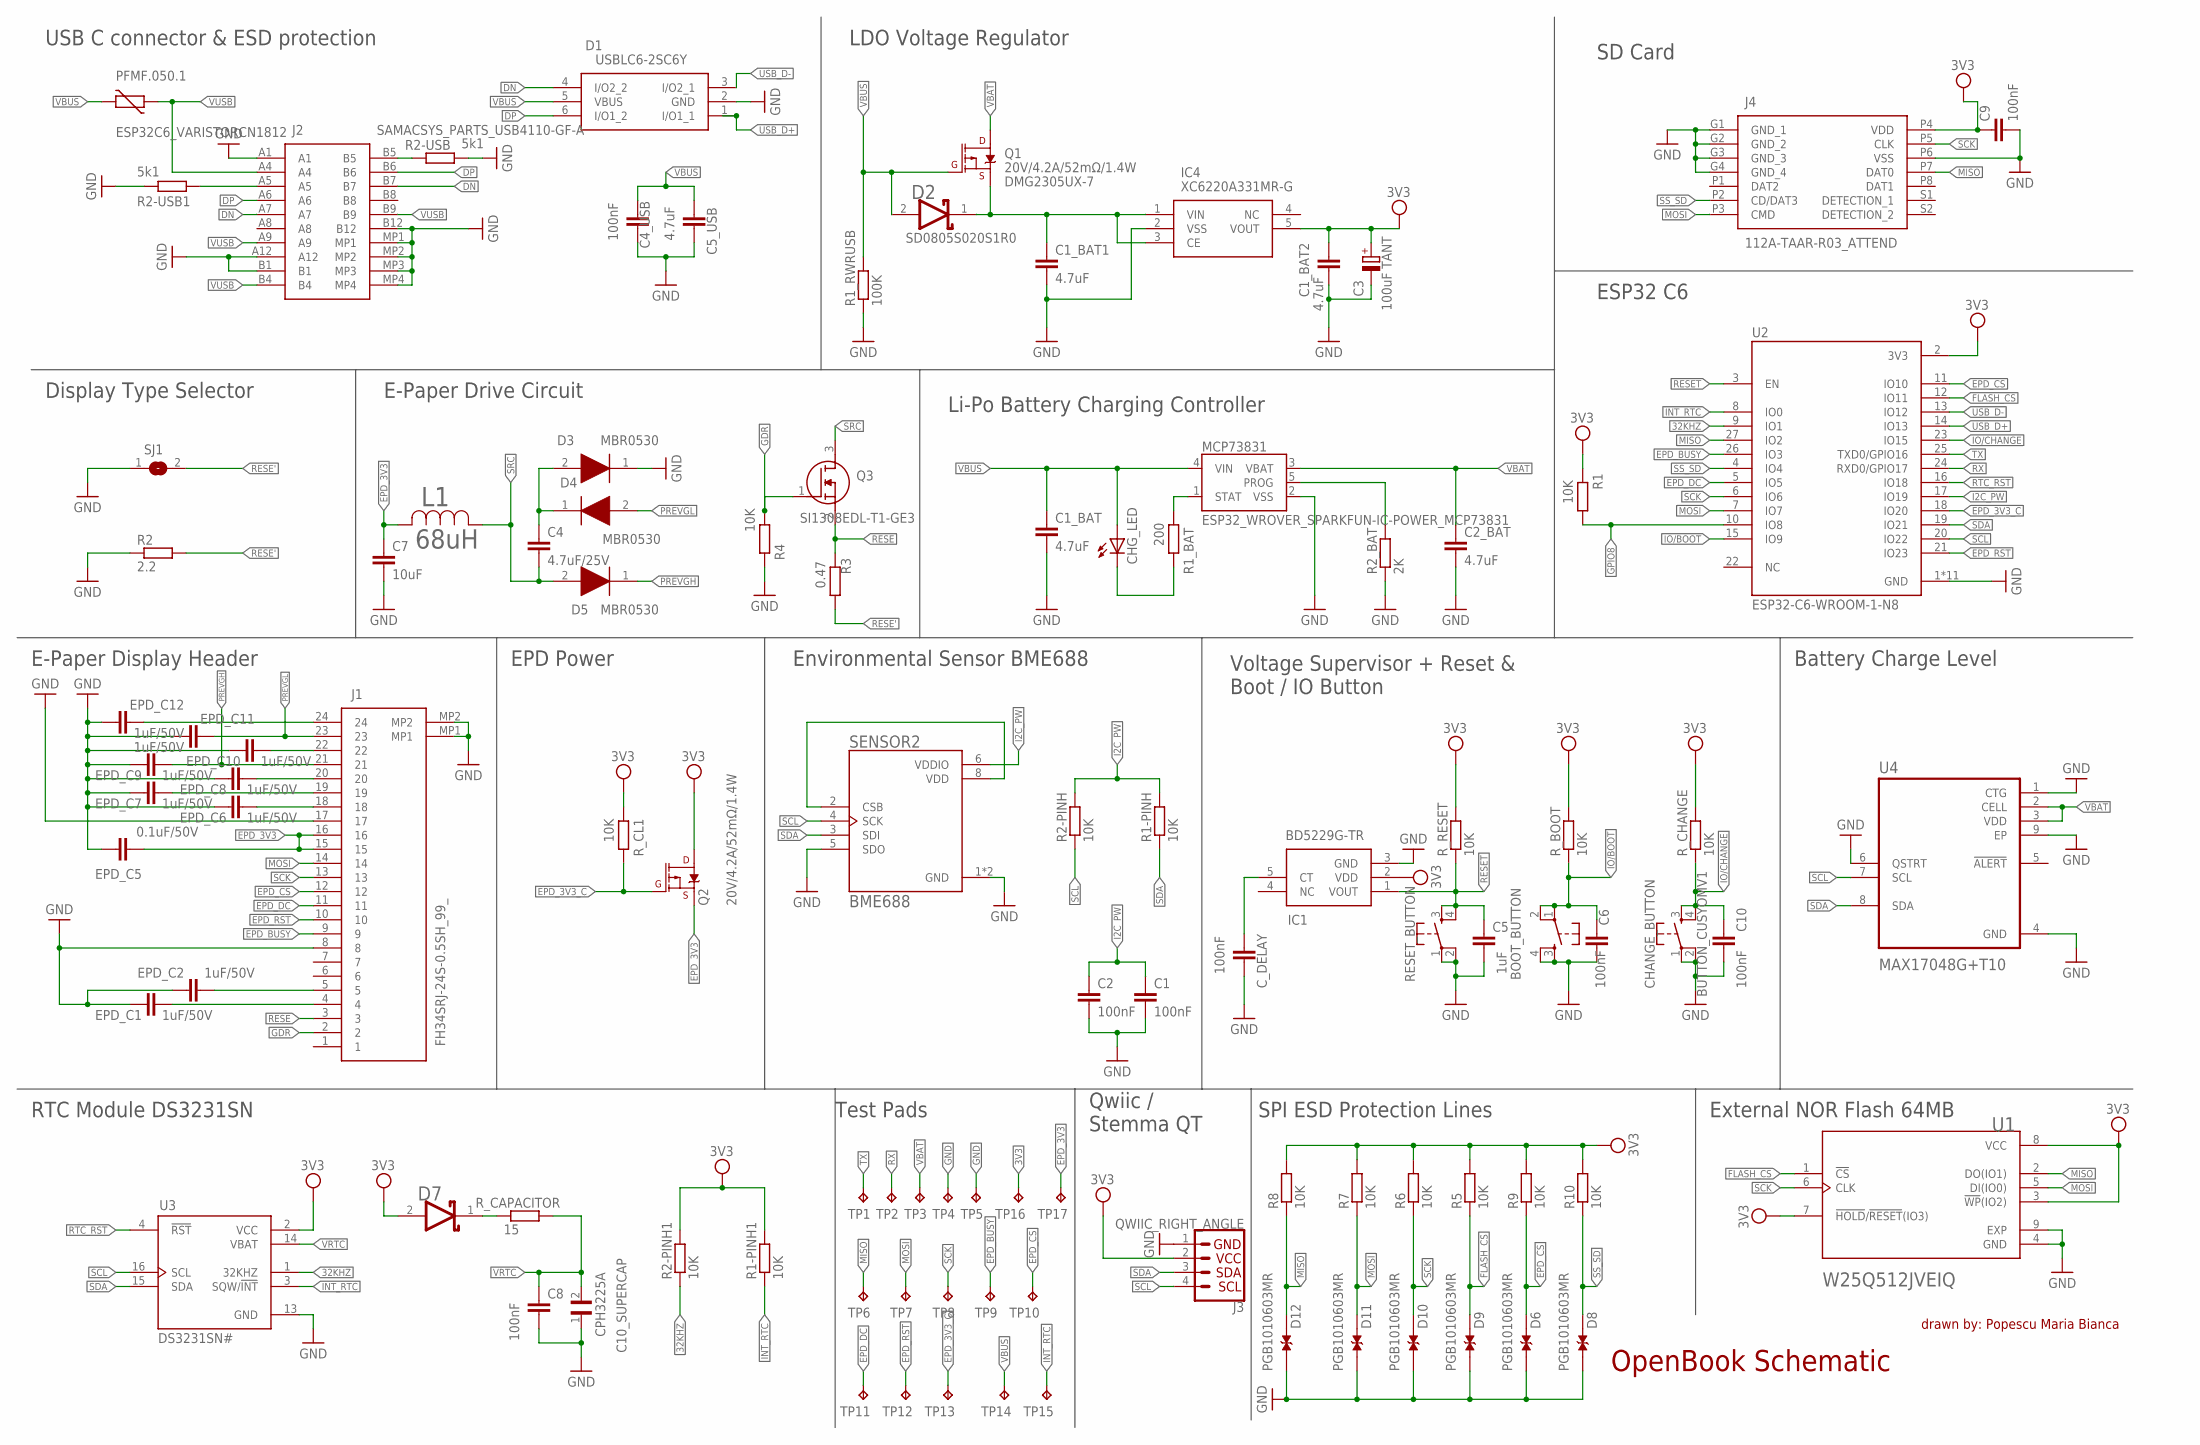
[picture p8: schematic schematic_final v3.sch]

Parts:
BOOT_BUTTON: BUTTON_CUSYOMV1; MYBUTTON
C1, C2, C4_USB, C6, C8, C9, C10: 100nF; EAGLE-LTSPICE_C0402
C1_BAT, C1_BAT1, C1_BAT2, C2_BAT, C5_USB: 4.7uF; EAGLE-LTSPICE_C0402
C3: 100uF TANT; RCL_CT3528
C4: 4.7uF/25V; EAGLE-LTSPICE_C0402
C5: 1uF; EAGLE-LTSPICE_C0402
C7: 10uF; EAGLE-LTSPICE_C0402
C10_SUPERCAP: CPH3225A; CAPCP3225X100N
CHANGE_BUTTON: BUTTON_CUSYOMV1; MYBUTTON
CHG_LED: ADAFRUIT_LEDCHIP-LED0603; ADAFRUIT_CHIP-LED0603
C_DELAY: 100nF; EAGLE-LTSPICE_C0402
D1: USBLC6-2SC6Y; SOT95P280X145-6N
D2: SD0805S020S1R0; ESP32_WROVER_AVX---SD0805S020S1R0_AVX_SD0805S020S1R0_0
D3, D4, D5: MBR0530; SOD3716X135N
D6, D8, D9, D10, D11, D12: PGB1010603MR; DIOC1608X36N
D7: ESP32_WROVER_AVX---SD0805S020S1R0_AVX_SD0805S020S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; ESP32_WROVER_AVX---SD0805S020S1R0_AVX_SD0805S020S1R0_0
EPD_C1, EPD_C2, EPD_C6, EPD_C7, EPD_C8, EPD_C9, EPD_C10, EPD_C11, EPD_C12: 1uF/50V; EAGLE-LTSPICE_C0402
EPD_C5: 0.1uF/50V; EAGLE-LTSPICE_C0402
IC1: BD5229G-TR; SOT95P280X125-5N
IC4: XC6220A331MR-G; SOT95P280X120-5N
J1: FH34SRJ-24S-0.5SH_99_; FH34SRJ24S05SH99
J2: SAMACSYS_PARTS_USB4110-GF-A; SAMACSYS_PARTS_USB4110GFA
J3: QWIIC_RIGHT_ANGLE; JST04_1MM_RA
J4: 112A-TAAR-R03_ATTEND; 112ATAARR03ATTEND
L1: 68uH; IND_4828-WE-TPC_WRE
MCP73831: ESP32_WROVER_SPARKFUN-IC-POWER_MCP73831; ESP32_WROVER_SPARKFUN-IC-POWER_SOT23-5
PFMF.050.1: ESP32C6_VARISTORCN1812; ESP32C6_VARISTOR_CT/CN1812
Q1, Q2: 20V/4.2A/52mΩ/1.4W; ESP32_WROVER_SPARKFUN-DISCRETESEMI_SOT23-3
Q3: SI1308EDL-T1-GE3; SOT65P210X110-3N
R1, R1-PINH, R1-PINH1, R2-PINH, R2-PINH1, R4, R5, R6, R7, R8, R9, R10: 10K; ESP32_WROVER_EAGLE-LTSPICE_R0402
R1_BAT: 200; ESP32_WROVER_EAGLE-LTSPICE_R0402
R1_RWRUSB: 100K; ESP32_WROVER_EAGLE-LTSPICE_R0402
R2: 2.2; ESP32_WROVER_EAGLE-LTSPICE_R0402
R2-USB, R2-USB1: 5k1; ESP32_WROVER_EAGLE-LTSPICE_R0402
R2_BAT: 2K; ESP32_WROVER_EAGLE-LTSPICE_R0402
R3: 0.47; ESP32_WROVER_EAGLE-LTSPICE_R0402
RESET_BUTTON: RESET_BUTTON; MYBUTTON
R_BOOT: 10K; ESP32_WROVER_EAGLE-LTSPICE_R0402
R_CAPACITOR: 15; ESP32_WROVER_EAGLE-LTSPICE_R0402
R_CHANGE: 10K; ESP32_WROVER_EAGLE-LTSPICE_R0402
R_CL1: 10K; ESP32_WROVER_EAGLE-LTSPICE_R0402
R_RESET: 10K; ESP32_WROVER_EAGLE-LTSPICE_R0402
SENSOR2: BME688; ESP32_WROVER_BME680_PSON80P300X300X100-8N
SJ1: SJ
TP1, TP2, TP3, TP4, TP5, TP6, TP7, TP8, TP9, TP10, TP11, TP12, TP13, TP14, TP15, TP16, TP17: TPTP20R; TP20R
U1: W25Q512JVEIQ; SON127P600X800X80-9N
U2: ESP32-C6-WROOM-1-N8; XCVR_ESP32-C6-WROOM-1-N8
U3: DS3231SN#; SOIC127P1032X265-16N
U4: MAX17048G+T10; SON50P200X200X80-9N

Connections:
3V3: C1_BAT2.1, C3.+, C9.1, D7.2 (ANODE), IC1.2 (VDD), IC4.5 (VOUT), J3.2, J4.P4 (VDD), Q2.3 (D), R1.2, R1-PINH1.2, R2-PINH1.2, R5.2, R6.2, R7.2, R8.2, R9.2, R10.2, R_BOOT.2, R_CHANGE.2, R_CL1.2, R_RESET.2, TP16.TP, U1.3 (!WP!(IO2)), U1.7 (!HOLD!/!RESET!(IO3)), U1.8 (VCC), U2.2 (3V3), U3.2 (VCC)
32KHZ: R2-PINH1.1, U2.9 (IO1), U3.1 (32KHZ)
DN: D1.4 (I/O2_2), J2.A7, J2.B7
DP: D1.6 (I/O1_2), J2.A6, J2.B6
EPD_3V3: C7.1, EPD_C5.2, J1.15, J1.16, L1.2, Q2.2 (S), TP17.TP
EPD_3V3_C: Q2.1 (G), R_CL1.1, TP13.TP, U2.18 (IO20)
EPD_BUSY: J1.9, TP9.TP, U2.26 (IO3)
EPD_CS: D6.2, J1.12, R9.1, TP10.TP, U2.11 (IO10)
EPD_DC: J1.11, TP11.TP, U2.5 (IO5)
EPD_RST: J1.10, TP12.TP, U2.21 (IO23)
FLASH_CS: D9.2, R5.1, U1.1 (!CS), U2.12 (IO11)
GDR: J1.2, Q3.1 (G), R4.2
GND: BOOT_BUTTON.3, BOOT_BUTTON.4, C1.2, C1_BAT.2, C1_BAT1.2, C1_BAT2.2, C2.2, C2_BAT.2, C3.-, C4_USB.2, C5.2, C5_USB.2, C6.2, C7.2, C8.2, C9.2, C10.2, C10_SUPERCAP.1, CHANGE_BUTTON.1, CHANGE_BUTTON.2, C_DELAY.2, D1.2 (GND), D3.1 (K), D6.1, D8.1, D9.1, D10.1, D11.1, D12.1, EPD_C1.1, EPD_C2.1, EPD_C5.1, EPD_C6.1, EPD_C7.1, EPD_C8.1, EPD_C9.1, EPD_C10.1, EPD_C11.1, EPD_C12.1, IC1.3 (GND), IC4.2 (VSS), J1.8, J1.17, J1.MP1, J1.MP2, J2.A1, J2.A12, J2.B1, J2.B12, J2.MP1, J2.MP2, J2.MP3, J2.MP4, J3.1, J4.G1 (GND_1), J4.G2 (GND_2), J4.G3 (GND_3), J4.G4 (GND_4), J4.P6 (VSS), MCP73831.2 (VSS), R1_RWRUSB.1, R2.1, R2-USB.2, R2-USB1.1, R2_BAT.1, R4.1, RESET_BUTTON.1, RESET_BUTTON.2, SENSOR2.1 (GND), SENSOR2.5 (SDO), SENSOR2.7 (GND), SJ1.1, TP4.TP, TP5.TP, U1.4 (GND), U1.9 (EXP), U2.1 (GND), U2.28 (GND), U2.29_1 (GND), U2.29_2 (GND), U2.29_3 (GND), U2.29_4 (GND), U2.29_5 (GND), U2.29_6 (GND), U2.29_7 (GND), U2.29_8 (GND), U2.29_9 (GND), U3.13 (GND), U4.1 (CTG), U4.4 (GND), U4.6 (QSTRT), U4.9 (EP)
GPIO8: R1.1, U2.10 (IO8)
I2C_PW: C1.1, C2.1, R1-PINH.2, R2-PINH.2, SENSOR2.6 (VDDIO), U2.17 (IO19)
INT_RTC: R1-PINH1.1, TP15.TP, U2.8 (IO0), U3.3 (SQW/!INT)
IO/BOOT: BOOT_BUTTON.1, BOOT_BUTTON.2, C6.1, R_BOOT.1, U2.15 (IO9)
IO/CHANGE: C10.1, CHANGE_BUTTON.3, CHANGE_BUTTON.4, R_CHANGE.1, U2.23 (IO15)
MISO: D12.2, J4.P7 (DAT0), R8.1, TP6.TP, U1.2 (DO(IO1)), U2.27 (IO2)
MOSI: D11.2, J1.14, J4.P3 (CMD), R7.1, TP7.TP, U1.5 (DI(IO0)), U2.7 (IO7)
unnamed: J2.A5, R2-USB1.2
unnamed: J2.B5, R2-USB.1
unnamed: SENSOR2.2 (CSB), SENSOR2.8 (VDD)
unnamed: C1_BAT1.1, D2.1 (CATHODE), IC4.1 (VIN), IC4.3 (CE), Q1.2 (S)
unnamed: D2.2 (ANODE), Q1.1 (G), R1_RWRUSB.2
unnamed: C4.1, D3.2 (A), D4.1 (K)
unnamed: MCP73831.1 (STAT), R1_BAT.2
unnamed: CHG_LED.C, R1_BAT.1
unnamed: MCP73831.5 (PROG), R2_BAT.2
unnamed: EPD_C2.2, J1.5
unnamed: EPD_C12.2, J1.24
unnamed: EPD_C1.2, J1.4
unnamed: EPD_C10.2, J1.22
unnamed: EPD_C8.2, J1.20
unnamed: EPD_C7.2, J1.19
unnamed: EPD_C6.2, J1.18
unnamed: C_DELAY.1, IC1.5 (CT)
unnamed: D7.1 (CATHODE), R_CAPACITOR.1
PREVGH: D5.1 (K), EPD_C9.2, J1.21
PREVGL: D4.2 (A), EPD_C11.2, J1.23
RESE: J1.3, Q3.2 (S), R3.2
RESE': R2.2, R3.1, SJ1.2
RESET: C5.1, IC1.1 (VOUT), RESET_BUTTON.3, RESET_BUTTON.4, R_RESET.1, U2.3 (EN)
RTC_RST: U2.16 (IO18), U3.4 (!RST)
RX: TP2.TP, U2.24 (RXD0/GPIO17)
SCK: D10.2, J1.13, J4.P5 (CLK), R6.1, TP8.TP, U1.6 (CLK), U2.6 (IO6)
SCL: J3.4, R2-PINH.1, SENSOR2.4 (SCK), U2.20 (IO22), U3.16 (SCL), U4.7 (SCL)
SDA: J3.3, R1-PINH.1, SENSOR2.3 (SDI), U2.19 (IO21), U3.15 (SDA), U4.8 (SDA)
SRC: C4.2, D5.2 (A), L1.1, Q3.3 (D)
SS_SD: D8.2, J4.P2 (CD/DAT3), R10.1, U2.4 (IO4)
TX: TP1.TP, U2.25 (TXD0/GPIO16)
USB_D+: D1.1 (I/O1_1), U2.14 (IO13)
USB_D-: D1.3 (I/O2_1), U2.13 (IO12)
VBAT: C2_BAT.1, MCP73831.3 (VBAT), Q1.3 (D), TP3.TP, U4.2 (CELL), U4.3 (VDD)
VBUS: C1_BAT.1, C4_USB.1, C5_USB.1, CHG_LED.A, D1.5 (VBUS), MCP73831.4 (VIN), PFMF.050.1.2, TP14.TP
VRTC: C8.1, C10_SUPERCAP.2, R_CAPACITOR.2, U3.14 (VBAT)
VUSB: J2.A4, J2.A9, J2.B4, J2.B9, PFMF.050.1.1

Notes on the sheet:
OpenBook Schematic
drawn by: Popescu Maria Bianca
USB C connector & ESD protection
LDO Voltage Regulator
SD Card
ESP32 C6
Li-Po Battery Charging Controller
E-Paper Drive Circuit
Display Type Selector
E-Paper Display Header
EPD Power
Environmental Sensor BME688
Voltage Supervisor + Reset & Boot / IO Button
Battery Charge Level
External NOR Flash 64MB
SPI ESD Protection Lines
Qwiic / Stemma QT
Test Pads
RTC Module DS3231SN

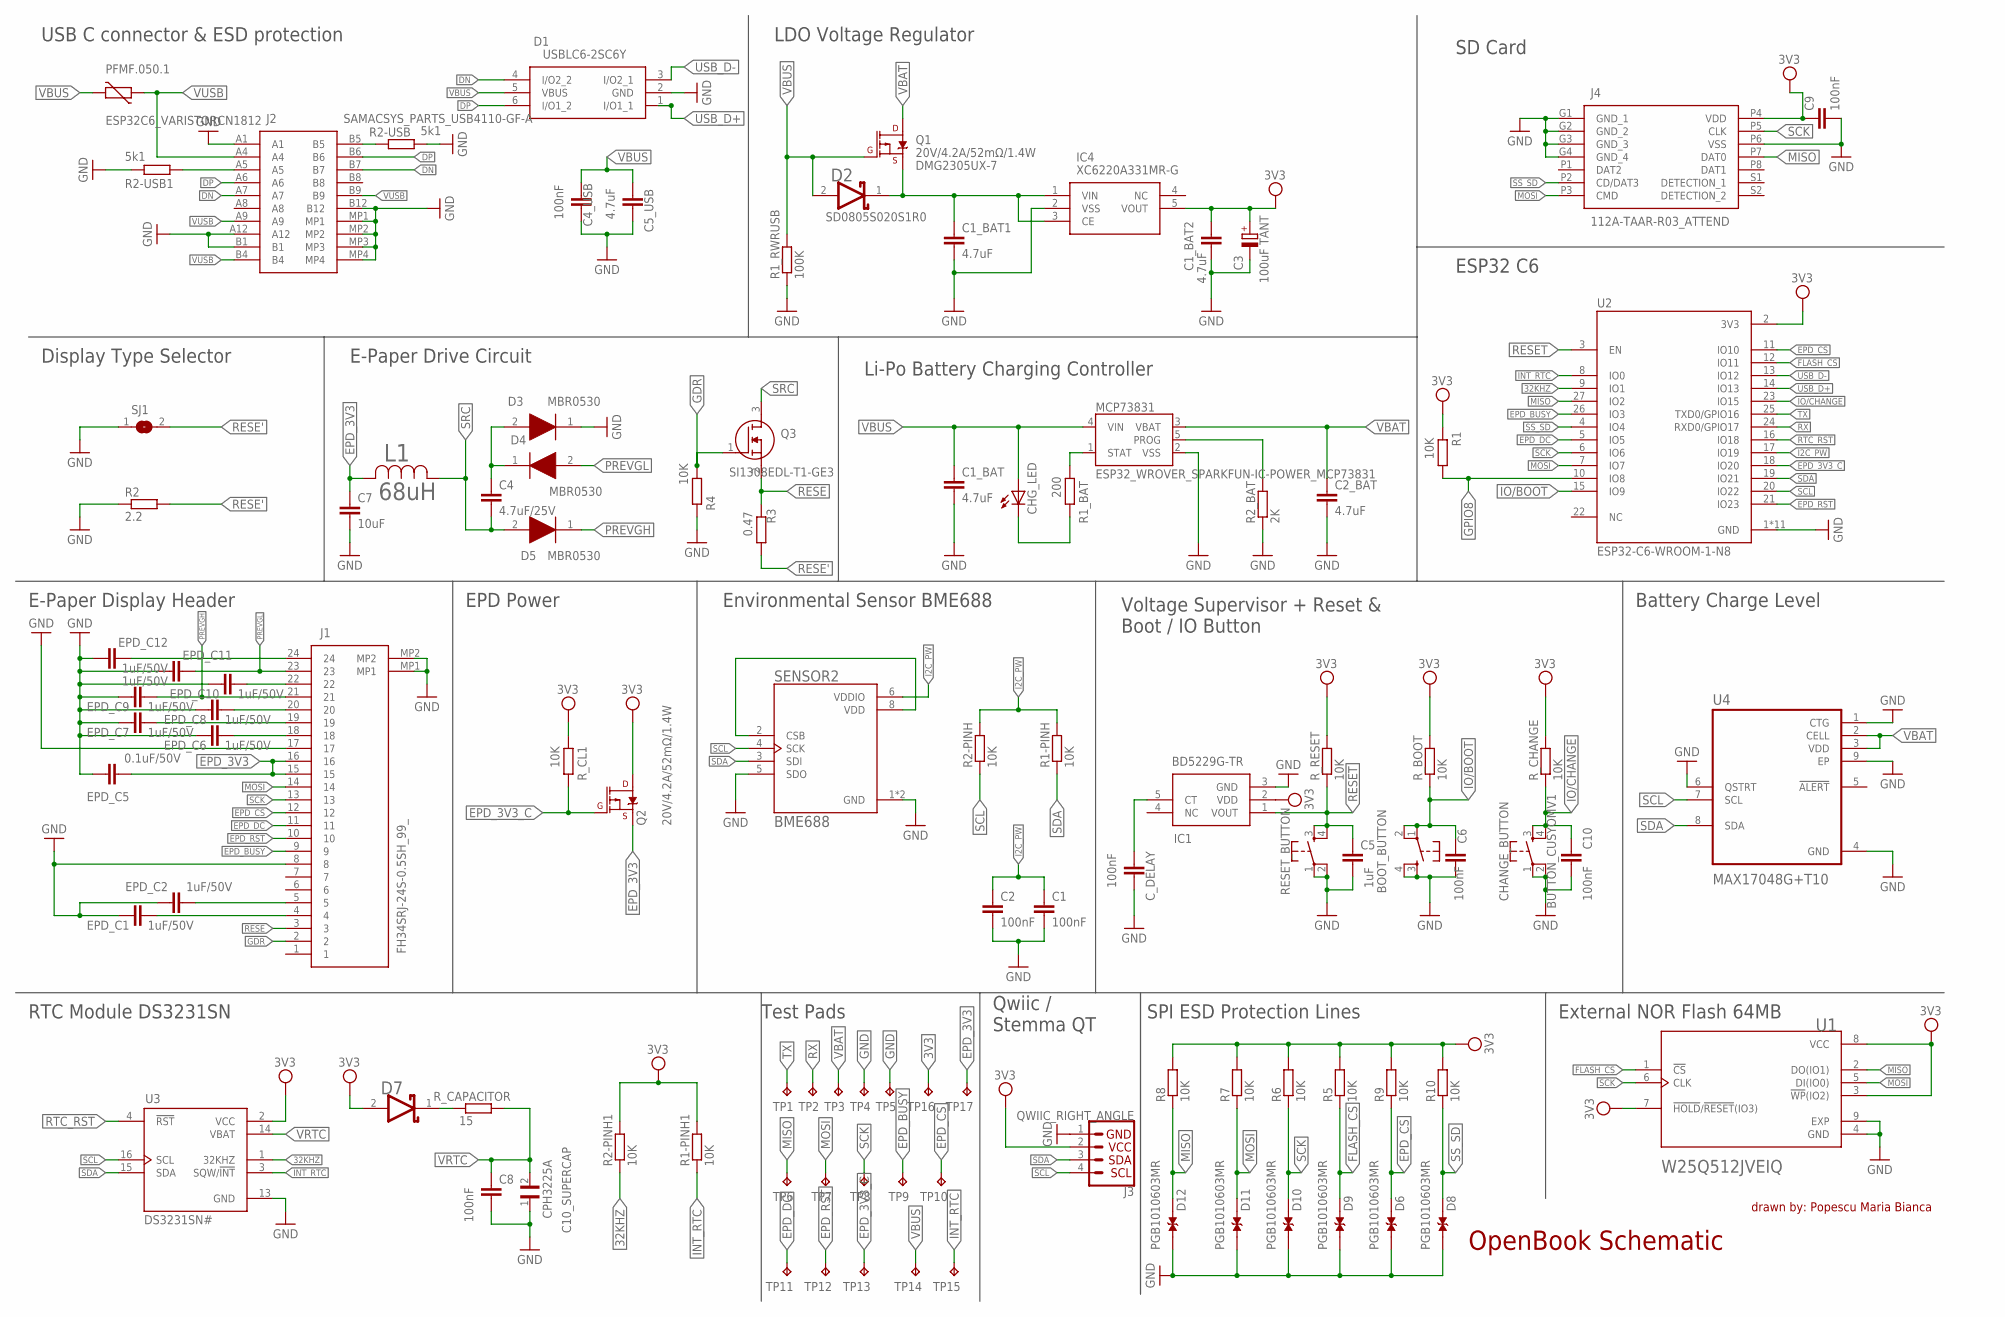
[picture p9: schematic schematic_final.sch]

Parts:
BOOT_BUTTON: BUTTON_CUSYOMV1; MYBUTTON
C1, C2, C4_USB, C6, C8, C9, C10: 100nF; EAGLE-LTSPICE_C0402
C1_BAT, C1_BAT1, C1_BAT2, C2_BAT, C5_USB: 4.7uF; EAGLE-LTSPICE_C0402
C3: 100uF TANT; RCL_CT3528
C4: 4.7uF/25V; EAGLE-LTSPICE_C0402
C5: 1uF; EAGLE-LTSPICE_C0402
C7: 10uF; EAGLE-LTSPICE_C0402
C10_SUPERCAP: CPH3225A; CAPCP3225X100N
CHANGE_BUTTON: BUTTON_CUSYOMV1; MYBUTTON
CHG_LED: ADAFRUIT_LEDCHIP-LED0603; ADAFRUIT_CHIP-LED0603
C_DELAY: 100nF; EAGLE-LTSPICE_C0402
D1: USBLC6-2SC6Y; SOT95P280X145-6N
D2: SD0805S020S1R0; ESP32_WROVER_AVX---SD0805S020S1R0_AVX_SD0805S020S1R0_0
D3, D4, D5: MBR0530; SOD3716X135N
D6, D8, D9, D10, D11, D12: PGB1010603MR; DIOC1608X36N
D7: ESP32_WROVER_AVX---SD0805S020S1R0_AVX_SD0805S020S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; ESP32_WROVER_AVX---SD0805S020S1R0_AVX_SD0805S020S1R0_0
EPD_C1, EPD_C2, EPD_C6, EPD_C7, EPD_C8, EPD_C9, EPD_C10, EPD_C11, EPD_C12: 1uF/50V; EAGLE-LTSPICE_C0402
EPD_C5: 0.1uF/50V; EAGLE-LTSPICE_C0402
IC1: BD5229G-TR; SOT95P280X125-5N
IC4: XC6220A331MR-G; SOT95P280X120-5N
J1: FH34SRJ-24S-0.5SH_99_; FH34SRJ24S05SH99
J2: SAMACSYS_PARTS_USB4110-GF-A; SAMACSYS_PARTS_USB4110GFA
J3: QWIIC_RIGHT_ANGLE; JST04_1MM_RA
J4: 112A-TAAR-R03_ATTEND; 112ATAARR03ATTEND
L1: 68uH; IND_4828-WE-TPC_WRE
MCP73831: ESP32_WROVER_SPARKFUN-IC-POWER_MCP73831; ESP32_WROVER_SPARKFUN-IC-POWER_SOT23-5
PFMF.050.1: ESP32C6_VARISTORCN1812; ESP32C6_VARISTOR_CT/CN1812
Q1, Q2: 20V/4.2A/52mΩ/1.4W; ESP32_WROVER_SPARKFUN-DISCRETESEMI_SOT23-3
Q3: SI1308EDL-T1-GE3; SOT65P210X110-3N
R1, R1-PINH, R1-PINH1, R2-PINH, R2-PINH1, R4, R5, R6, R7, R8, R9, R10: 10K; ESP32_WROVER_EAGLE-LTSPICE_R0402
R1_BAT: 200; ESP32_WROVER_EAGLE-LTSPICE_R0402
R1_RWRUSB: 100K; ESP32_WROVER_EAGLE-LTSPICE_R0402
R2: 2.2; ESP32_WROVER_EAGLE-LTSPICE_R0402
R2-USB, R2-USB1: 5k1; ESP32_WROVER_EAGLE-LTSPICE_R0402
R2_BAT: 2K; ESP32_WROVER_EAGLE-LTSPICE_R0402
R3: 0.47; ESP32_WROVER_EAGLE-LTSPICE_R0402
RESET_BUTTON: RESET_BUTTON; MYBUTTON
R_BOOT: 10K; ESP32_WROVER_EAGLE-LTSPICE_R0402
R_CAPACITOR: 15; ESP32_WROVER_EAGLE-LTSPICE_R0402
R_CHANGE: 10K; ESP32_WROVER_EAGLE-LTSPICE_R0402
R_CL1: 10K; ESP32_WROVER_EAGLE-LTSPICE_R0402
R_RESET: 10K; ESP32_WROVER_EAGLE-LTSPICE_R0402
SENSOR2: BME688; ESP32_WROVER_BME680_PSON80P300X300X100-8N
SJ1: SJ
TP1, TP2, TP3, TP4, TP5, TP6, TP7, TP8, TP9, TP10, TP11, TP12, TP13, TP14, TP15, TP16, TP17: TPTP20R; TP20R
U1: W25Q512JVEIQ; SON127P600X800X80-9N
U2: ESP32-C6-WROOM-1-N8; XCVR_ESP32-C6-WROOM-1-N8
U3: DS3231SN#; SOIC127P1032X265-16N
U4: MAX17048G+T10; SON50P200X200X80-9N

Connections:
3V3: C1_BAT2.1, C3.+, C9.1, D7.2 (ANODE), IC1.2 (VDD), IC4.5 (VOUT), J3.2, J4.P4 (VDD), Q2.3 (D), R1.2, R1-PINH1.2, R2-PINH1.2, R5.2, R6.2, R7.2, R8.2, R9.2, R10.2, R_BOOT.2, R_CHANGE.2, R_CL1.2, R_RESET.2, TP16.TP, U1.3 (!WP!(IO2)), U1.7 (!HOLD!/!RESET!(IO3)), U1.8 (VCC), U2.2 (3V3), U3.2 (VCC)
32KHZ: R2-PINH1.1, U2.9 (IO1), U3.1 (32KHZ)
DN: D1.4 (I/O2_2), J2.A7, J2.B7
DP: D1.6 (I/O1_2), J2.A6, J2.B6
EPD_3V3: C7.1, EPD_C5.2, J1.15, J1.16, L1.2, Q2.2 (S), TP17.TP
EPD_3V3_C: Q2.1 (G), R_CL1.1, TP13.TP, U2.18 (IO20)
EPD_BUSY: J1.9, TP9.TP, U2.26 (IO3)
EPD_CS: D6.2, J1.12, R9.1, TP10.TP, U2.11 (IO10)
EPD_DC: J1.11, TP11.TP, U2.5 (IO5)
EPD_RST: J1.10, TP12.TP, U2.21 (IO23)
FLASH_CS: D9.2, R5.1, U1.1 (!CS), U2.12 (IO11)
GDR: J1.2, Q3.1 (G), R4.2
GND: BOOT_BUTTON.3, BOOT_BUTTON.4, C1.2, C1_BAT.2, C1_BAT1.2, C1_BAT2.2, C2.2, C2_BAT.2, C3.-, C4_USB.2, C5.2, C5_USB.2, C6.2, C7.2, C8.2, C9.2, C10.2, C10_SUPERCAP.1, CHANGE_BUTTON.1, CHANGE_BUTTON.2, C_DELAY.2, D1.2 (GND), D3.1 (K), D6.1, D8.1, D9.1, D10.1, D11.1, D12.1, EPD_C1.1, EPD_C2.1, EPD_C5.1, EPD_C6.1, EPD_C7.1, EPD_C8.1, EPD_C9.1, EPD_C10.1, EPD_C11.1, EPD_C12.1, IC1.3 (GND), IC4.2 (VSS), J1.8, J1.17, J1.MP1, J1.MP2, J2.A1, J2.A12, J2.B1, J2.B12, J2.MP1, J2.MP2, J2.MP3, J2.MP4, J3.1, J4.G1 (GND_1), J4.G2 (GND_2), J4.G3 (GND_3), J4.G4 (GND_4), J4.P6 (VSS), MCP73831.2 (VSS), R1_RWRUSB.1, R2.1, R2-USB.2, R2-USB1.1, R2_BAT.1, R4.1, RESET_BUTTON.1, RESET_BUTTON.2, SENSOR2.1 (GND), SENSOR2.5 (SDO), SENSOR2.7 (GND), SJ1.1, TP4.TP, TP5.TP, U1.4 (GND), U1.9 (EXP), U2.1 (GND), U2.28 (GND), U2.29_1 (GND), U2.29_2 (GND), U2.29_3 (GND), U2.29_4 (GND), U2.29_5 (GND), U2.29_6 (GND), U2.29_7 (GND), U2.29_8 (GND), U2.29_9 (GND), U3.13 (GND), U4.1 (CTG), U4.4 (GND), U4.6 (QSTRT), U4.9 (EP)
GPIO8: R1.1, U2.10 (IO8)
I2C_PW: C1.1, C2.1, R1-PINH.2, R2-PINH.2, SENSOR2.6 (VDDIO), U2.17 (IO19)
INT_RTC: R1-PINH1.1, TP15.TP, U2.8 (IO0), U3.3 (SQW/!INT)
IO/BOOT: BOOT_BUTTON.1, BOOT_BUTTON.2, C6.1, R_BOOT.1, U2.15 (IO9)
IO/CHANGE: C10.1, CHANGE_BUTTON.3, CHANGE_BUTTON.4, R_CHANGE.1, U2.23 (IO15)
MISO: D12.2, J4.P7 (DAT0), R8.1, TP6.TP, U1.2 (DO(IO1)), U2.27 (IO2)
MOSI: D11.2, J1.14, J4.P3 (CMD), R7.1, TP7.TP, U1.5 (DI(IO0)), U2.7 (IO7)
unnamed: J2.A5, R2-USB1.2
unnamed: J2.B5, R2-USB.1
unnamed: SENSOR2.2 (CSB), SENSOR2.8 (VDD)
unnamed: C1_BAT1.1, D2.1 (CATHODE), IC4.1 (VIN), IC4.3 (CE), Q1.2 (S)
unnamed: D2.2 (ANODE), Q1.1 (G), R1_RWRUSB.2
unnamed: C4.1, D3.2 (A), D4.1 (K)
unnamed: MCP73831.1 (STAT), R1_BAT.2
unnamed: CHG_LED.C, R1_BAT.1
unnamed: MCP73831.5 (PROG), R2_BAT.2
unnamed: EPD_C2.2, J1.5
unnamed: EPD_C12.2, J1.24
unnamed: EPD_C1.2, J1.4
unnamed: EPD_C10.2, J1.22
unnamed: EPD_C8.2, J1.20
unnamed: EPD_C7.2, J1.19
unnamed: EPD_C6.2, J1.18
unnamed: C_DELAY.1, IC1.5 (CT)
unnamed: D7.1 (CATHODE), R_CAPACITOR.1
PREVGH: D5.1 (K), EPD_C9.2, J1.21
PREVGL: D4.2 (A), EPD_C11.2, J1.23
RESE: J1.3, Q3.2 (S), R3.2
RESE': R2.2, R3.1, SJ1.2
RESET: C5.1, IC1.1 (VOUT), RESET_BUTTON.3, RESET_BUTTON.4, R_RESET.1, U2.3 (EN)
RTC_RST: U2.16 (IO18), U3.4 (!RST)
RX: TP2.TP, U2.24 (RXD0/GPIO17)
SCK: D10.2, J1.13, J4.P5 (CLK), R6.1, TP8.TP, U1.6 (CLK), U2.6 (IO6)
SCL: J3.4, R2-PINH.1, SENSOR2.4 (SCK), U2.20 (IO22), U3.16 (SCL), U4.7 (SCL)
SDA: J3.3, R1-PINH.1, SENSOR2.3 (SDI), U2.19 (IO21), U3.15 (SDA), U4.8 (SDA)
SRC: C4.2, D5.2 (A), L1.1, Q3.3 (D)
SS_SD: D8.2, J4.P2 (CD/DAT3), R10.1, U2.4 (IO4)
TX: TP1.TP, U2.25 (TXD0/GPIO16)
USB_D+: D1.1 (I/O1_1), U2.14 (IO13)
USB_D-: D1.3 (I/O2_1), U2.13 (IO12)
VBAT: C2_BAT.1, MCP73831.3 (VBAT), Q1.3 (D), TP3.TP, U4.2 (CELL), U4.3 (VDD)
VBUS: C1_BAT.1, C4_USB.1, C5_USB.1, CHG_LED.A, D1.5 (VBUS), MCP73831.4 (VIN), PFMF.050.1.2, TP14.TP
VRTC: C8.1, C10_SUPERCAP.2, R_CAPACITOR.2, U3.14 (VBAT)
VUSB: J2.A4, J2.A9, J2.B4, J2.B9, PFMF.050.1.1

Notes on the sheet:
OpenBook Schematic
drawn by: Popescu Maria Bianca
USB C connector & ESD protection
LDO Voltage Regulator
SD Card
ESP32 C6
Li-Po Battery Charging Controller
E-Paper Drive Circuit
Display Type Selector
E-Paper Display Header
EPD Power
Environmental Sensor BME688
Voltage Supervisor + Reset & Boot / IO Button
Battery Charge Level
External NOR Flash 64MB
SPI ESD Protection Lines
Qwiic / Stemma QT
Test Pads
RTC Module DS3231SN

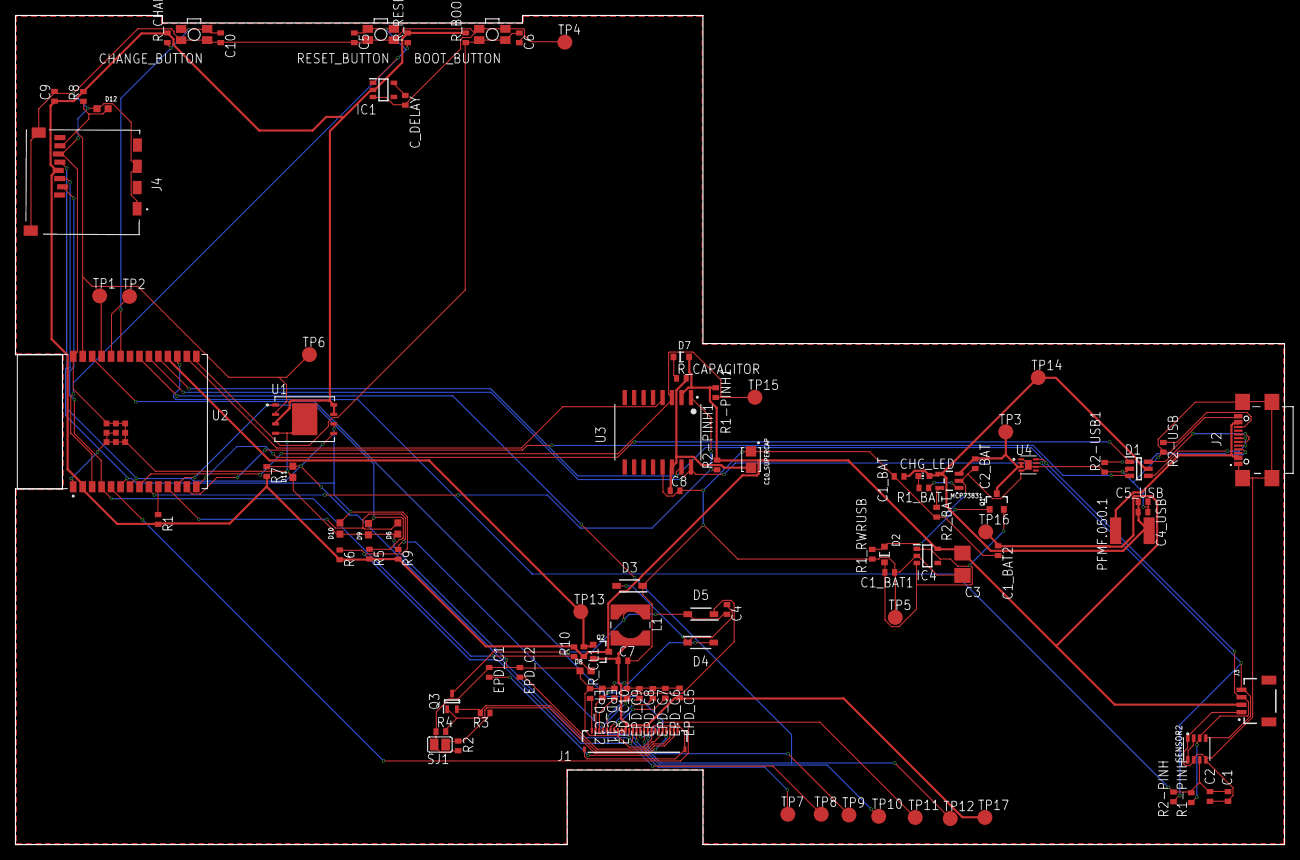
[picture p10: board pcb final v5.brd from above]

Board: 2 copper layers, 170.2 x 111.2 mm, 103 parts (0 on the bottom side), 57 nets.

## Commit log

2025-04-05 added project
    [Pick and place.csv, bom.csv, pcb final.brd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]
2025-04-15 resolved issues
    [pcb final v5.brd, schematic_final v3.sch]

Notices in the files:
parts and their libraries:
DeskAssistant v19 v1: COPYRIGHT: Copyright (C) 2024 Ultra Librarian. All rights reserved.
